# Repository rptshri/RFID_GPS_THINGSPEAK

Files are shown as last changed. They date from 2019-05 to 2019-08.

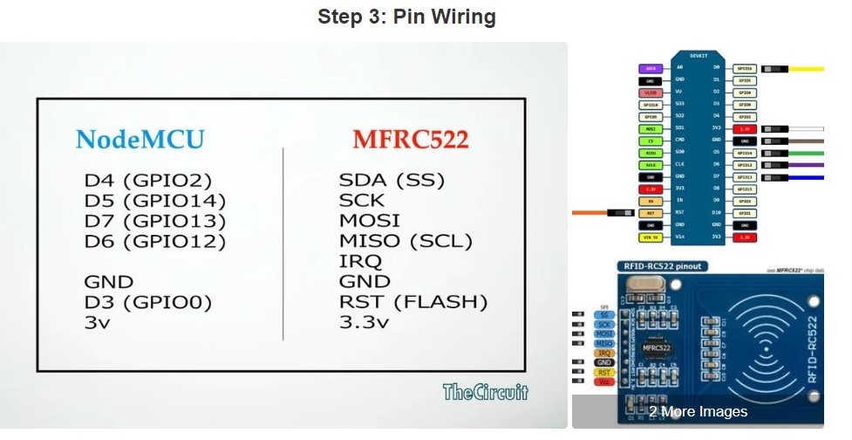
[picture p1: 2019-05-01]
Documentation/RC522_pinout.jpg

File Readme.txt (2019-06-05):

hi there!

UID (blue tag):     36 55 C5 F7
UID (White tag):    30 B0 C7 3A 
UID (White tag):    91 9F E5 2F

a

References:

RC522:      https://www.instructables.com/id/MFRC522-RFID-Reader-Interfaced-With-NodeMCU/

RC522               NodeMCU
SS(1)               D8(gpio15)             1,2,5,6,7
SCK(2)              D5(gpio14)
MOSI(3)             D7(gpio13)
MISO(4)             D6(gpio12)
IRQ(5)              ~
GND(6)              GND
RST(7)              D1(gpio5)----(NC)
3.3v(8)             +3.3V

I2C LCD:   https://www.instructables.com/id/I2C-LCD-on-NodeMCU-V2-With-Arduino-IDE/
library link:   https://github.com/fdebrabander/Arduino-LiquidCrystal-I2C-library
LCD                 NodeMCU
VCC                 +3.3v
GND                 GND         
SDA                 D2
SCL                 D1

GPS:    https://circuitdigest.com/microcontroller-projects/interfacing-gps-with-nodemcu-esp12

GPS Pins            NodeMCU
VCC                 +3.3V
RX                  D4
TX                  D3
GND                 GND

for finding distance between two lat and long
https://andrew.hedges.name/experiments/haversine/
dlon = lon2 - lon1 
dlat = lat2 - lat1 
a = (sin(dlat/2))^2 + cos(lat1) * cos(lat2) * (sin(dlon/2))^2 
c = 2 * atan2( sqrt(a), sqrt(1-a) ) 
d = R * c (where R is the radius of the Earth)

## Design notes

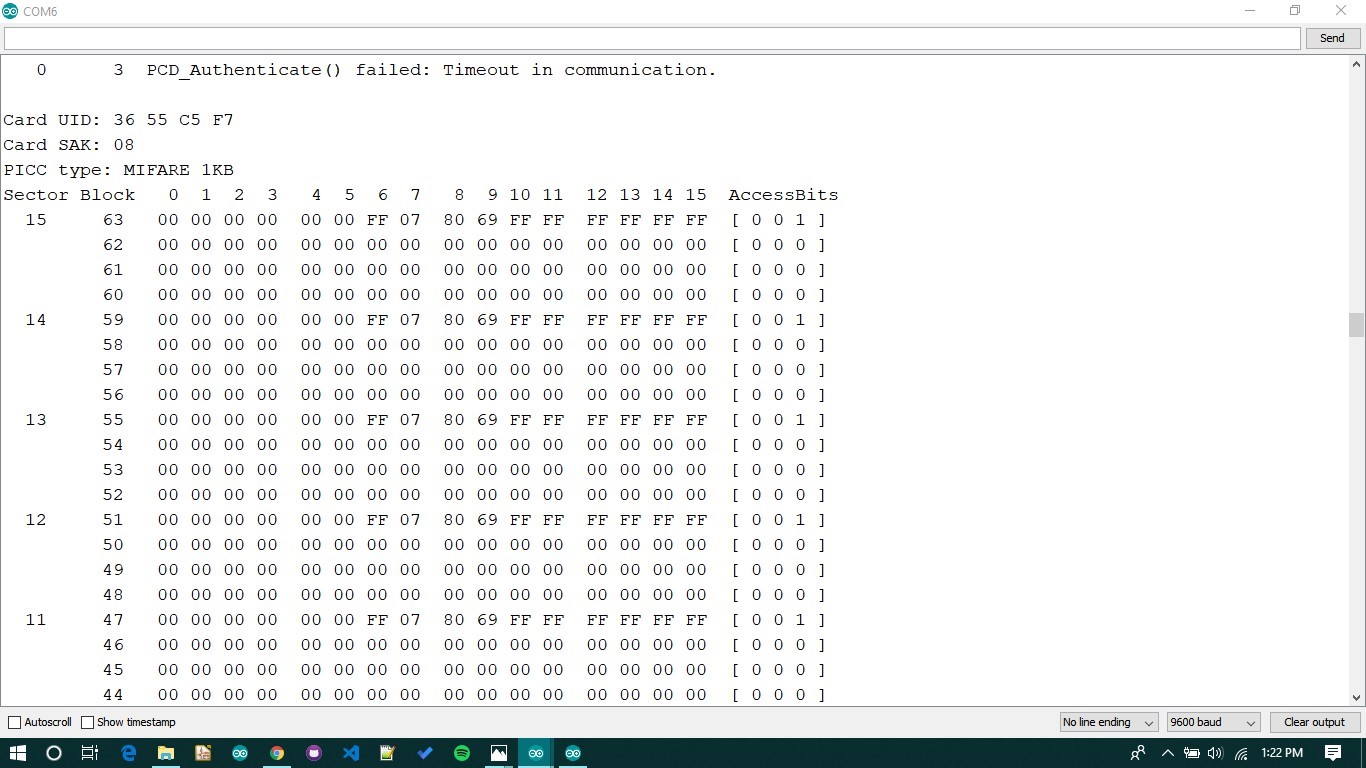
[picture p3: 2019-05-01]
Documentation/photos/getting_UUID_of_Tags.jpg

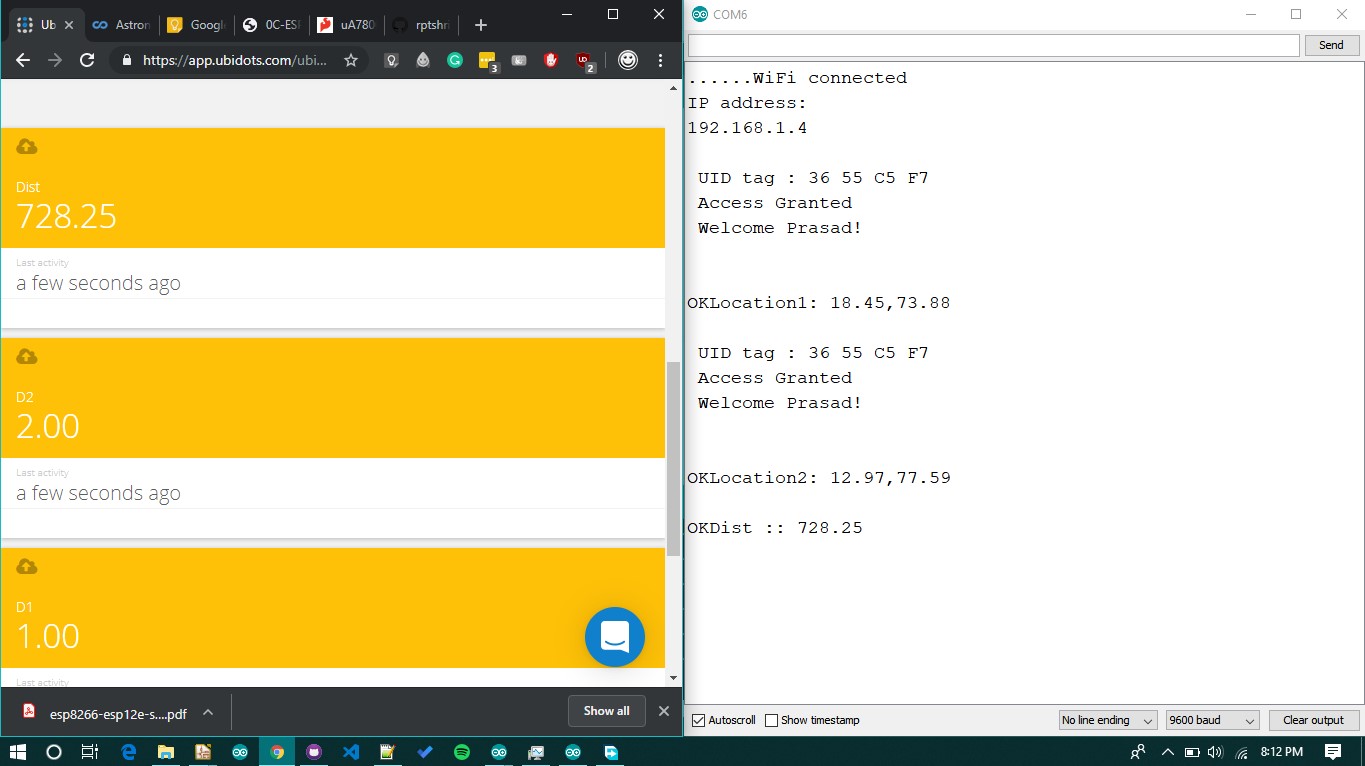
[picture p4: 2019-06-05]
Documentation/photos/cloud vs terminal.jpg

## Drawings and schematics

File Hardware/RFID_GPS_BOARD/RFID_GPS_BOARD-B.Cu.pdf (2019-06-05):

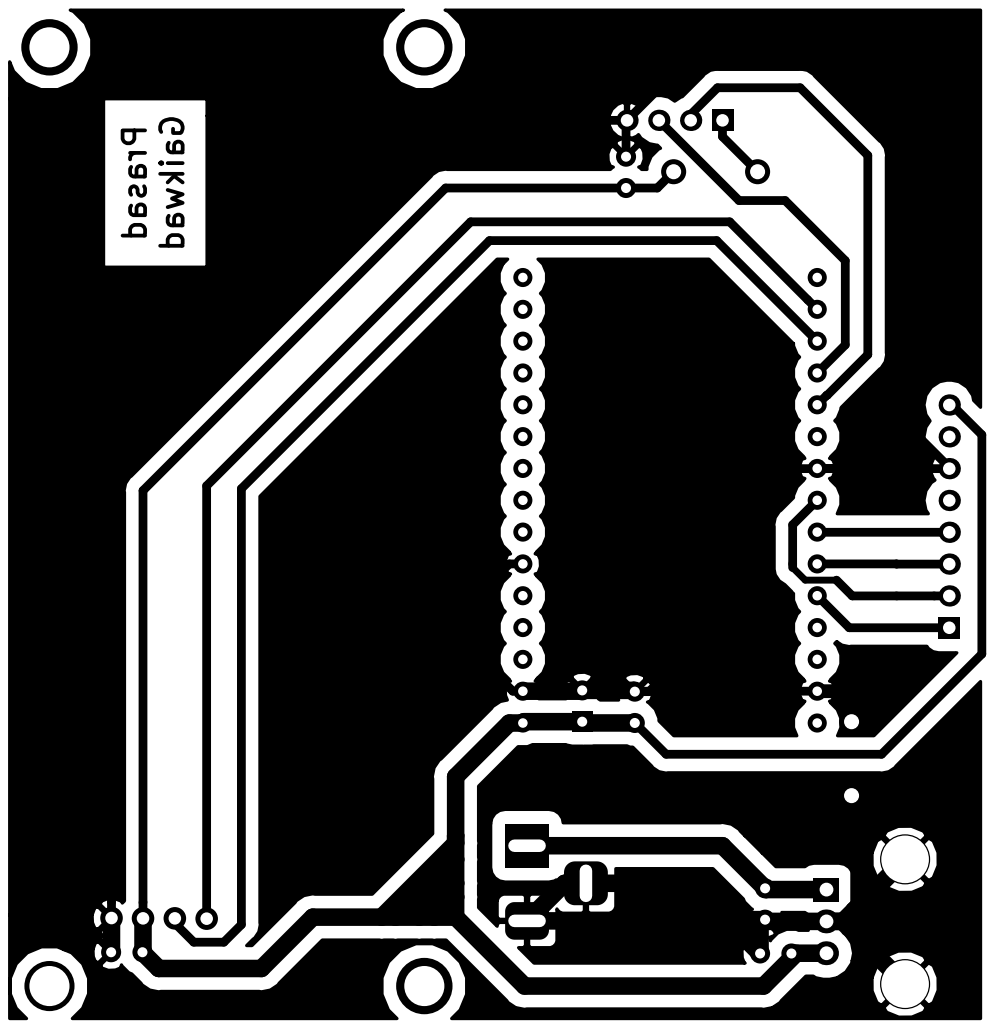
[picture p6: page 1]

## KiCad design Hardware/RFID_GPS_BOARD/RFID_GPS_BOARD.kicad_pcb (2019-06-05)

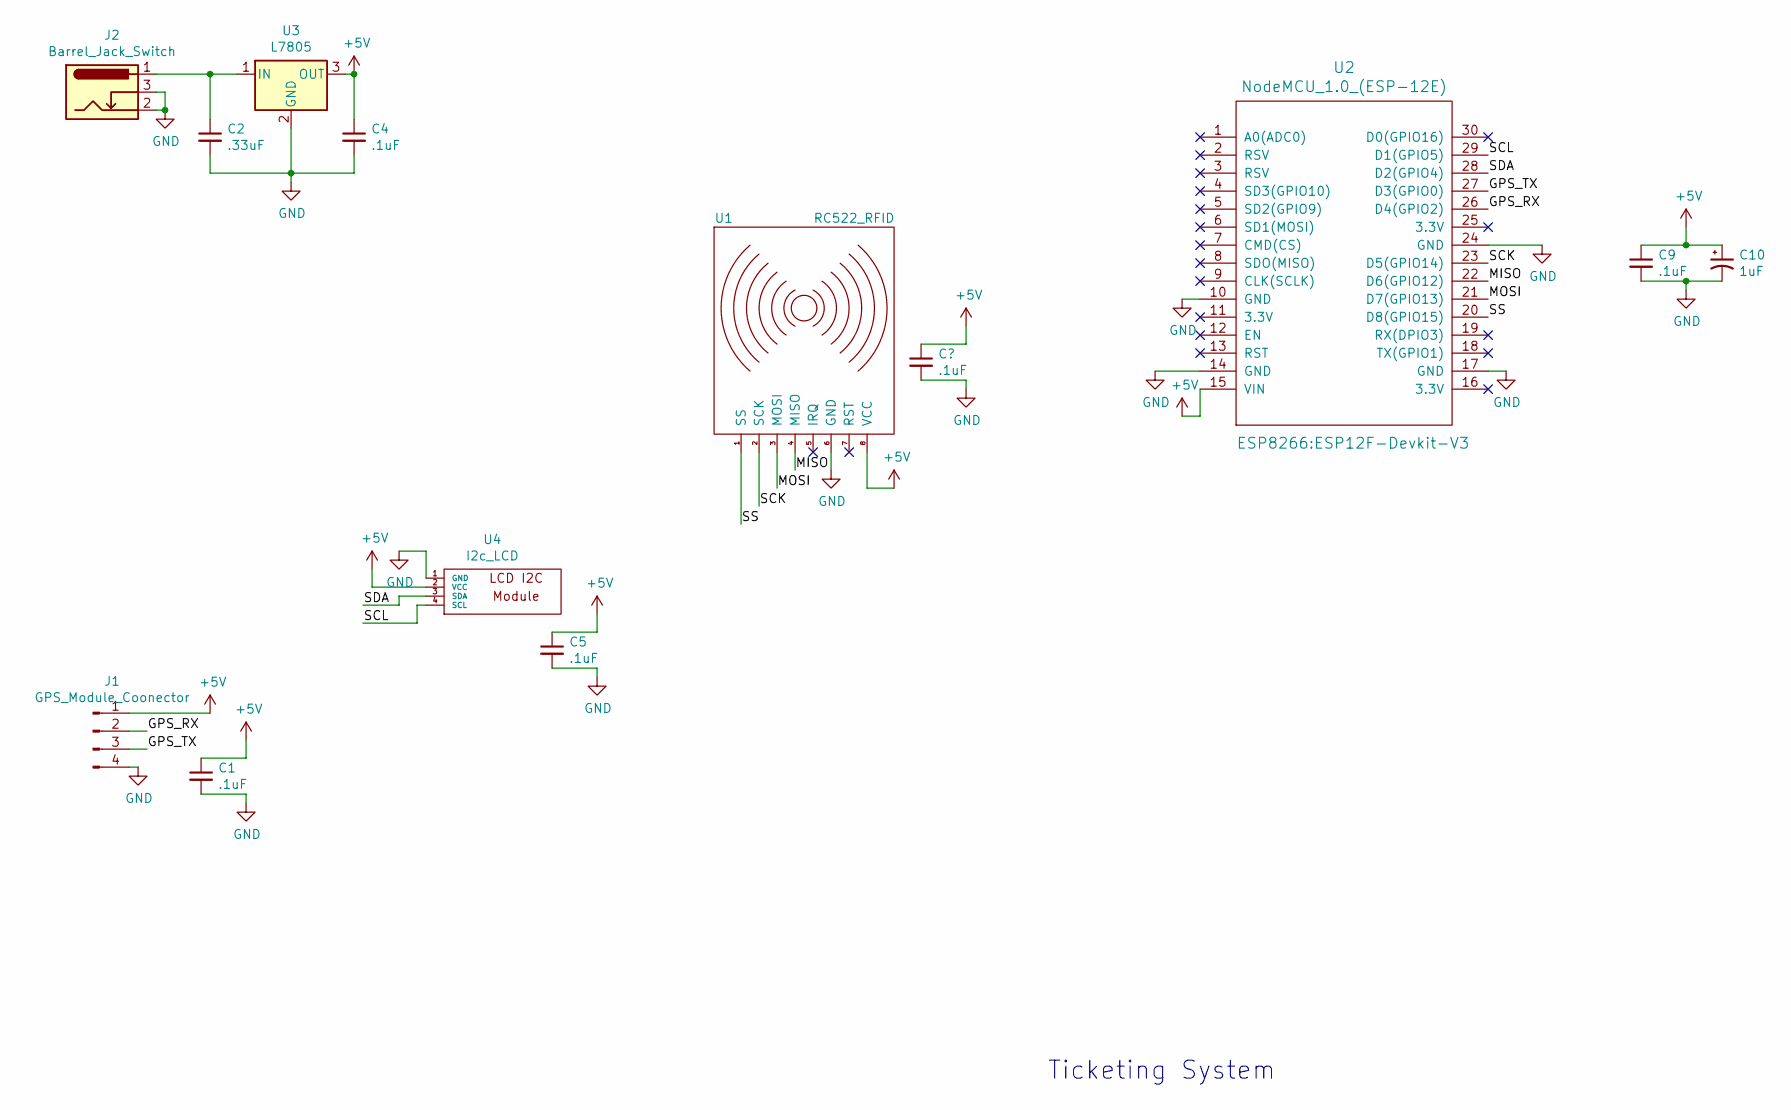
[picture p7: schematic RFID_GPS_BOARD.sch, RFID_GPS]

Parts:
C1, C4, C5, C9: .1uF; C_Disc_D3.0mm_W1.6mm_P2.50mm
C2: .33uF; C_Disc_D3.0mm_W1.6mm_P2.50mm
C10: 1uF; CP_Radial_D5.0mm_P2.50mm
J1: GPS_Module_Coonector; PinHeader_1x04_P2.54mm_Vertical
J2: Barrel_Jack_Switch
U1: RC522_RFID; PinHeader_1x08_P2.54mm_Vertical
U2: NodeMCU_1.0_(ESP-12E); ESP12F-Devkit-V3
U3: L7805; TO-220-3_Vertical
U4: I2c_LCD; LCD_I2C

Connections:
+5V: C1.1, C4.1, C5.1, C9.1, C10.1, J1.1, U1.8 (VCC), U2.15 (VIN), U3.3 (OUT), U4.2 (VCC)
/GPS_RX: J1.2, U2.26 (D4(GPIO2))
/GPS_TX: J1.3, U2.27 (D3(GPIO0))
/MISO: U1.4 (MISO), U2.22 (D6(GPIO12))
/MOSI: U1.3 (MOSI), U2.21 (D7(GPIO13))
/SCK: U1.2 (SCK), U2.23 (D5(GPIO14))
/SCL: U2.29 (D1(GPIO5)), U4.4 (SCL)
/SDA: U2.28 (D2(GPIO4)), U4.3 (SDA)
/SS: U1.1 (SS), U2.20 (D8(GPIO15))
GND: C1.2, C2.2, C4.2, C5.2, C9.2, C10.2, J1.4, J2.2, J2.3, U1.6 (GND), U2.10 (GND), U2.14 (GND), U2.17 (GND), U2.24 (GND), U3.2 (GND), U4.1 (GND)
unnamed: C2.1, J2.1, U3.1 (IN)

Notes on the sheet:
Ticketing System

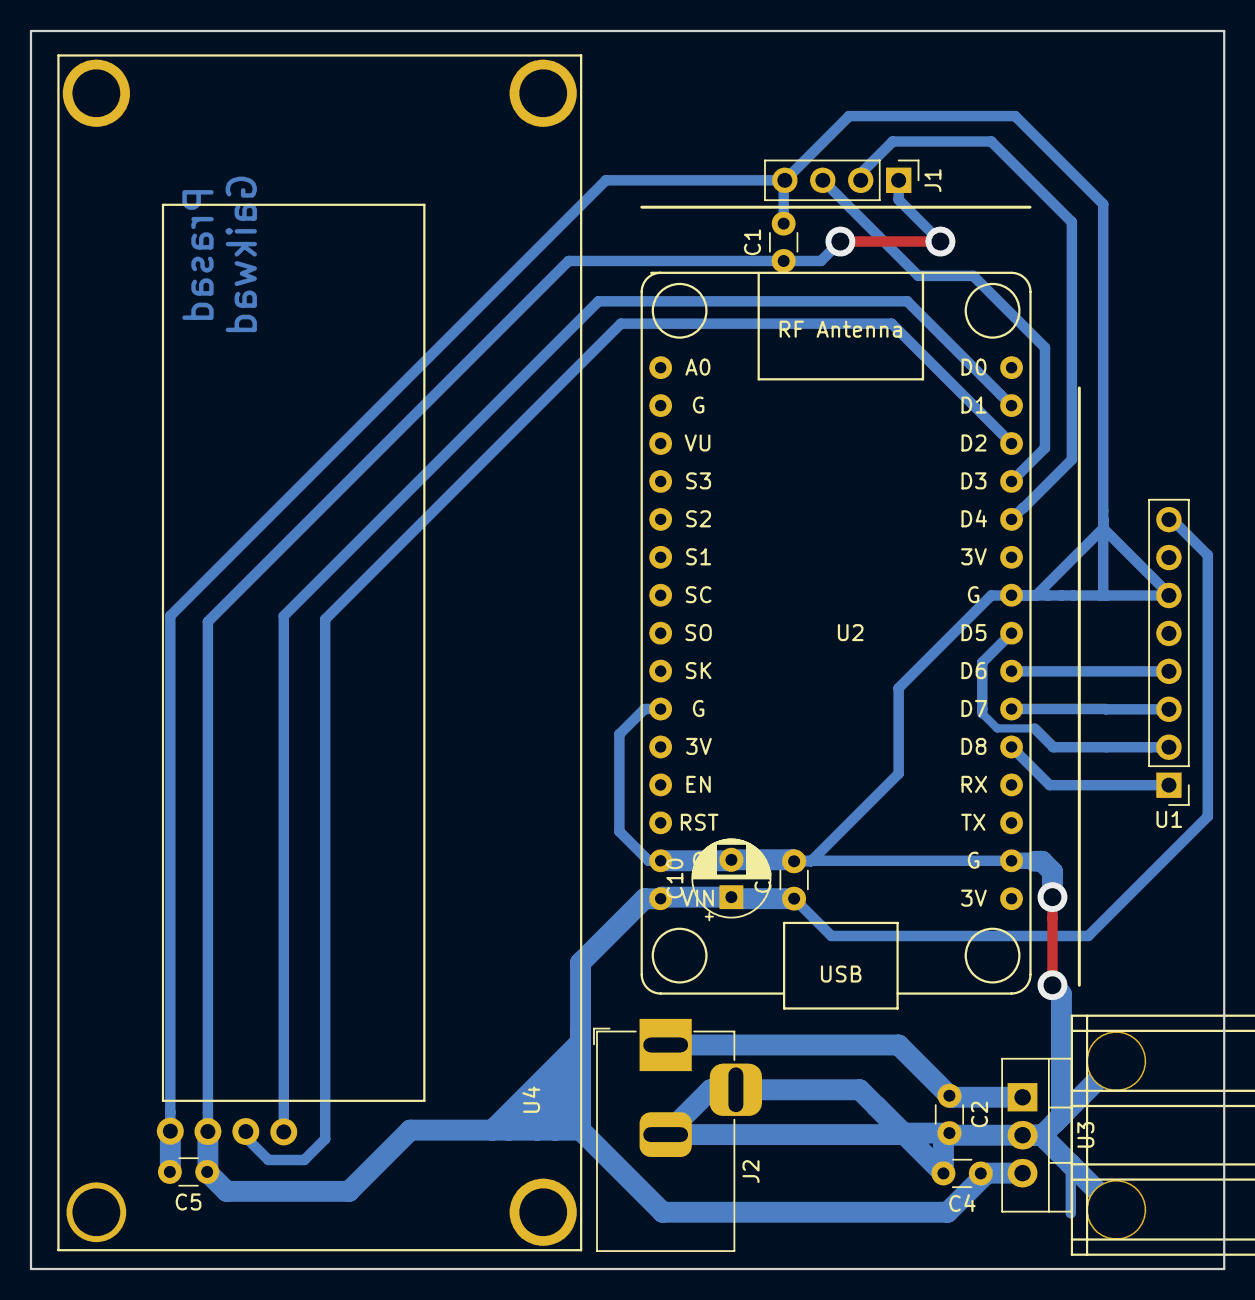
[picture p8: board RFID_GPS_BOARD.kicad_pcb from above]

Board: 2 copper layers, 79.9 x 82.9 mm, 12 parts (0 on the bottom side), 11 nets.

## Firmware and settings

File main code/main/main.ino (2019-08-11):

#include "UbidotsMicroESP8266.h"
#include <TinyGPS++.h>
#include <SoftwareSerial.h>
static const int RXPin = 0, TXPin = 2;
static const uint32_t GPSBaud = 9600; // Change according to your device
// The TinyGPS++ object
TinyGPSPlus gps;
// The serial connection to the GPS device
SoftwareSerial ss(RXPin, TXPin);

#include <Wire.h>
#include <LiquidCrystal_I2C.h>
// Set the LCD address to 0x27 for a 16 chars and 2 line display
LiquidCrystal_I2C lcd(0x27, 16, 2);

#include <SPI.h>
#include <MFRC522.h>
#define SS_PIN 15 //D8
#define RST_PIN 0//D3 (NC)
MFRC522 mfrc522(SS_PIN, RST_PIN);   // Create MFRC522 instance.
int statuss = 0;
int out = 0;


#define TOKEN  "A1E-E9Civ0PCH1OO4TRZEUz99w2qCnWR9c"  // Put here your Ubidots TOKEN
#define WIFISSID "SPAM" // Put here your Wi-Fi SSID
#define PASSWORD "12345678" // Put here your Wi-Fi password

Ubidots client(TOKEN);

double _lat1, _lng1;
double _lat2, _lng2;
int dummy1 = 1;
int dummy2 = 2;
char context[25];
int flag = 0;
boolean one = false;

unsigned long previousMillis = 0;     // last time data was send
const long interval = 15000;           // data transfer interval

void calDistance();
int deg2rad();
void lcdprint();
void RFIDcheck();

void setup()
{
  Serial.begin(9600);
  ss.begin(GPSBaud);
  client.wifiConnection(WIFISSID, PASSWORD);
  SPI.begin();      // Initiate  SPI bus
  mfrc522.PCD_Init();   // Initiate MFRC522
  lcd.begin();
  lcd.backlight();
  lcd.print("Hello!!!");
  //  lcdprint();
}

void loop()
{
  flag = flag % 2;
  while (ss.available() > 0) {
    if (gps.encode(ss.read())) {
      unsigned long currentMillis = millis();

      RFIDcheck();

      if (flag == 1 && one == true)
      {
        if (gps.location.isValid())
        {
          _lat1 = gps.location.lat();
          _lng1 = gps.location.lng();
          sprintf(context, "lat=%.4f$lng=%.4f", _lat1, _lng1);

          client.add("D1", dummy1, context);
          client.sendAll(true);
          Serial.print(F("Location1: "));
          Serial.print(_lat1);
          Serial.print(F(","));
          Serial.print(_lng1);
          Serial.println();
          lcd.clear();
          lcd.setCursor(0, 0);
          lcd.print("lat1=");
          lcd.print(_lat1);
          lcd.setCursor(0, 1);
          lcd.print("lng1=");
          lcd.print(_lng1);
          delay(1000);
        }
        else
        {
          Serial.print(F("INVALID"));
        }
        one = false;
      }

      if (flag == 0 && one == true)
      {
        _lat2 = 12.9716;
        _lng2 = 77.5946;
        sprintf(context, "lat=%.4f$lng=%.4f", _lat2, _lng2);

        client.add("D2", dummy2, context);
        client.sendAll(true);

        Serial.print(F("Location2: "));
        Serial.print(_lat2);
        Serial.print(F(","));
        Serial.print(_lng2);
        one = false;
        lcd.clear();
        lcd.setCursor(0, 0);
        lcd.print("lat2=");
        lcd.print(_lat2);
        lcd.setCursor(0, 1);
        lcd.print("lng2=");
        lcd.print(_lng2);
        Serial.println();
        delay(1000);
        calDistance();
      }

    }
  }

  if (millis() > 5000 && gps.charsProcessed() < 10)
  {
    Serial.println(F("No GPS detected: check wiring."));
    while (true);
  }
}

void calDistance()
{
  double dlon, dlat;
  double a, c, d;
  dlon = deg2rad(_lng2 - _lng1);
  dlat = deg2rad(_lat2 - _lat1);
  a = sq(sin(dlat / 2)) + cos(deg2rad(_lat1)) * cos(deg2rad(_lat2)) * sq(sin(dlon / 2));
  c = 2 * atan2( sqrt(a), sqrt(1 - a) );
  d = 6378.1 * c    ;                         //(where R is the radius of the Earth);
  client.add("Dist", d);
  client.sendAll(true);
  Serial.print("Dist :: ");
  Serial.println(d);
  lcd.clear();
  lcd.setCursor(0, 0);
  lcd.print("Distance:  ");
  lcd.setCursor(0, 1);
  lcd.print(d);
  delay(1000);
}

double deg2rad( double degree)
{
  return (degree * (PI / 180));
}

void lcdprint()
{
  lcd.begin();
  lcd.backlight();
  lcd.print("Hello, world!");
}

void RFIDcheck()
{
  if ( ! mfrc522.PICC_IsNewCardPresent())
  {
    return;
  }
  // Select one of the cards
  if ( ! mfrc522.PICC_ReadCardSerial())
  {
    return;
  }
  //Show UID on serial monitor
  Serial.println();
  Serial.print(" UID tag :");
  String content = "";
  byte letter;
  for (byte i = 0; i < mfrc522.uid.size; i++)
  {
    Serial.print(mfrc522.uid.uidByte[i] < 0x10 ? " 0" : " ");
    Serial.print(mfrc522.uid.uidByte[i], HEX);
    content.concat(String(mfrc522.uid.uidByte[i] < 0x10 ? " 0" : " "));
    content.concat(String(mfrc522.uid.uidByte[i], HEX));
  }
  content.toUpperCase();
  lcd.setCursor(0, 0);
  lcd.print(content.substring(1));
  Serial.println();
  delay(500);

  if (content.substring(1) == "36 55 C5 F7") //change UID of the card that you want to give access
  {
    flag++;
    one = true;
    Serial.println(" Access Granted ");
    Serial.println(" Welcome Prasad! ");
    lcd.setCursor(0, 1);
    lcd.print(" Access Granted! ");
    delay(1000);
    Serial.println();
    statuss = 1;
  }
  else
  {
    Serial.println(" Access Denied ");
    lcd.setCursor(0, 1);
    lcd.print(" Access Denied!!! ");
    delay(1000);
  }
}

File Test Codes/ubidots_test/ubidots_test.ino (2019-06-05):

#include "UbidotsMicroESP8266.h"

#define TOKEN  "A1E-N6Gf7ttRwp6BjyaG2EEQDLtXbTg94V"  // Put here your Ubidots TOKEN
#define WIFISSID "SPAM" // Put here your Wi-Fi SSID
#define PASSWORD "12345678" // Put here your Wi-Fi password

Ubidots client(TOKEN);


char str_temp[25];
char str_temp2[25];

void setup() {
  Serial.begin(9600);
  client.wifiConnection(WIFISSID, PASSWORD);
  client.setDebug(true); // Uncomment this line to set DEBUG on
  //  pinMode(pin, INPUT);
}
void loop() {
  char context[25];
  int latitude = 124;
    int lat1= 50;
  


  client.add("str_temp", latitude);
    client.add("str_temp2", lat1);
  client.sendAll(true);
  delay(100);
}

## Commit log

2019-06-05 almost done
    [RFID_GPS_BOARD.kicad_pcb, RFID_GPS_BOARD.sch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]
2019-06-05 completed project final
    [RFID_GPS_BOARD.sch]
2019-06-05 libararies added
    [_saved_RFID_GPS_BOARD.sch]
2019-08-11 final update
    [RFID_GPS_BOARD.sch, _saved_RFID_GPS_BOARD.sch]
